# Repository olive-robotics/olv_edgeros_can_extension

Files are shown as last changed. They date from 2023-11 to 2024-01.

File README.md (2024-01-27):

# Olive Robotics EdgeROS SOM01-X CAN Carrier Board

## Overview

This repository contains the KiCad project files for a carrier board designed to interface with the Olive Robotics EdgeROS SOM01-X. The carrier board connects via the 2x18 pin connector on the EdgeROS and provides a CAN interface.



## Features

- 2x18 pin connector for interfacing with EdgeROS SOM01-X
- CAN interface
- Designed using KiCad

## Prerequisites

- KiCad 7.0.1 or higher
- Basic understanding of PCB design and electronics

## Getting Started

1. **Clone the Repository**: Clone or download this repository to your local machine.
2. **Open the Project**: Navigate to the directory where you cloned the repository and open the KiCad project file.
3. **Review the Schematic**: Open the schematic editor to review the connections.
4. **Inspect the Layout**: Open the PCB layout editor to review or modify the board layout.
5. **Generate Gerber Files**: Once you are satisfied with the design, generate the Gerber files for manufacturing.

## Usage

1. **Assembly**: Solder the 2x18 pin connector and the USB 2.0 interface components onto the carrier board.
2. **Connection**: Connect the carrier board to the EdgeROS SOM01-X using the 2x18 pin connector.
3. **Testing**: Power up the EdgeROS and connect a CAN device to test the interface.

## Contributing

If you find any issues or have suggestions for improvements, feel free to open an issue or submit a pull request.

## License

This project is open-source and available under the MIT License. See the `LICENSE.md` file for more information.

## Contact

For any questions or inquiries, please contact Olive Robotics at [contact@olive-robotics.com](mailto:contact@olive-robotics.com).

---

Happy building! 🤖

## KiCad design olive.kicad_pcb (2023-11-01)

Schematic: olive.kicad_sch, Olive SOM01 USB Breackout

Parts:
C1, C3, C4: 100nF; C_0402_1005Metric
C2: 220uF 6.3v Case(mm)3228; CP_EIA-3528-21_Kemet-B
D1, D2: LED; LED_0603_1608Metric
H1, H2, H3, H4: MountingHole_Pad; MountingHole_2.2mm_M2_ISO7380_Pad
J2: Conn_02x18_Odd_Even; PinHeader_2x18_P1.27mm_Vertical_SMD
J3: Conn_01x04_Male; Molex_PicoBlade_53261-0471_1x04-1MP_P1.25mm_Horizontal
R1: 10K; R_0402_1005Metric
R2: 120R (DNP); R_0402_1005Metric
R3: 1K; R_0402_1005Metric
U1: TCAN1051HGV-Q1; Texas_DRB0008A-X

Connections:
+3V3: C4.1, J2.4, U1.5 (SHDN)
+5V: C1.1, C2.1, C3.1, D1.2 (A), J2.2, J3.4, U1.3 (VCC)
/CAN_RX: J2.17, U1.4 (RXD)
/CAN_ST: J2.3, U1.8 (S)
/CAN_TX: J2.19, U1.1 (TXD)
/I2C1_SCL: J2.15
/I2C1_SDA: J2.13
/I2C6_SCL: J2.16
/I2C6_SDA: J2.14
/OSD_ADC_0: J2.36
/OSD_ADC_1: J2.34
/OSD_ADC_2: J2.32
/OSD_ADC_3: J2.30
/OSD_ADC_4: J2.28
/OSD_ADC_5: J2.26
/OSD_ADC_6: J2.24
/OSD_ADC_7: J2.22
/OSD_PWM_0: D2.2 (A), J2.21
/OSD_PWM_1: J2.23
/OSD_PWM_2: J2.25
/OSD_PWM_3: J2.27
/OSD_PWM_4: J2.29
/OSD_PWM_5: J2.31
/OSD_PWM_6: J2.33
/OSD_PWM_7: J2.35
/SPI-CLK: J2.7
/SPI-MISO: J2.9
/SPI-MOSI: J2.11
/SPI-NSS: J2.5
/TTL_RXD: J2.18
/TTL_TXD: J2.20
/USB_OSD1_D_N: J2.8
/USB_OSD1_D_P: J2.6
/USB_OSD_D_N: J2.12
/USB_OSD_D_P: J2.10
GND: C1.2, C2.2, C3.2, C4.2, H1.1, H2.1, H3.1, H4.1, J2.1, J3.1, J3.MP, R1.1, R3.1, U1.2 (GND)
unnamed: D1.1 (K), R1.2
unnamed: D2.1 (K), R3.2
unnamed: J3.2, R2.1, U1.6 (CANL)
unnamed: J3.3, R2.2, U1.7 (CANH)

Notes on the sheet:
PWR LEDs
Note: 3.3v Max 1800mA +5.0v Max 2000mA
Olive Robotics SOM01-X EdgeROS SOM Platform (c) Copyright, Olive Robotics GmbH, 2021 - Dec. All Rights Reserved.
CAN TX-RX LED
Screw Pads
Note: To control the PWM signals, use the following files in the Oive Robotics OLIX RT Linux Kernel. /sys/class/pwm/pwmchip4/pwm3/duty_cycle /sys/class/pwm/pwmchip4/pwm2/duty_cycle /sys/class/pwm/pwmchip4/pwm1/duty_cycle /sys/class/pwm/pwmchip4/pwm0/duty_cycle /sys/class/pwm/pwmchip0/pwm3/duty_cycl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
Note: To read the adc data, use the following files in the Oive Robotics OLIX RT Linux Kernel. /sys/bus/iio/devices/iio:device0/in_voltage1_raw /sys/bus/iio/devices/iio:device0/in_voltage2_raw /sys/bus/iio/devices/iio:device0/in_voltage4_raw /sys/bus/iio/devices/iio:device0/in_voltage5_raw /sys/bus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
Note: DO Not USE! USB_OSD_D_N & USB_OSD_D_P

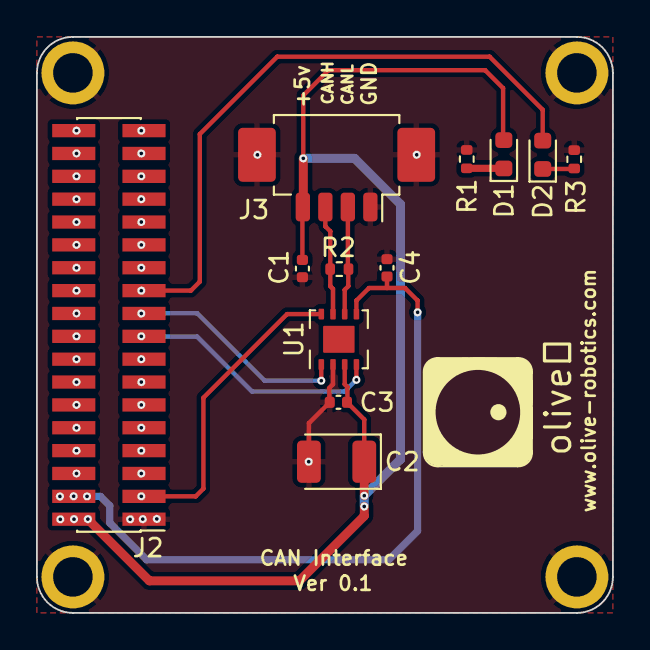
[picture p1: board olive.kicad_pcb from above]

Board: 2 copper layers, 32.0 x 32.0 mm, 16 parts (0 on the bottom side), 11 nets.

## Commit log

2023-11-01 The Can driver
    [olive.kicad_pcb, olive.kicad_sch]
2024-01-27 Update README.md
    Added the 3D image of the board to the README.md
